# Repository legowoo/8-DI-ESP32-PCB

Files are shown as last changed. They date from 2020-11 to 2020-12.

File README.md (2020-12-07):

# 8-DI-ESP32-PCB
A printed circuit board that enables a ESP32 to interface with digital inputs up to 28VDC.

# Features
- 8 Galvanically isolated inputs
- Pluggable terminal blocks for connecting sensors
- Supports 12 and 24VDC sensors
- ESD protected inputs
- Reverse polarity protection
- Over current protection

# Technical Specification
- ESP32 Input voltage 5-16VDC
- Sensor Input voltage 5-28VDC (with 3/4W input resistors)
- Maximum input current draw 12mA
- Maximum board power draw ~10W

# Schematic
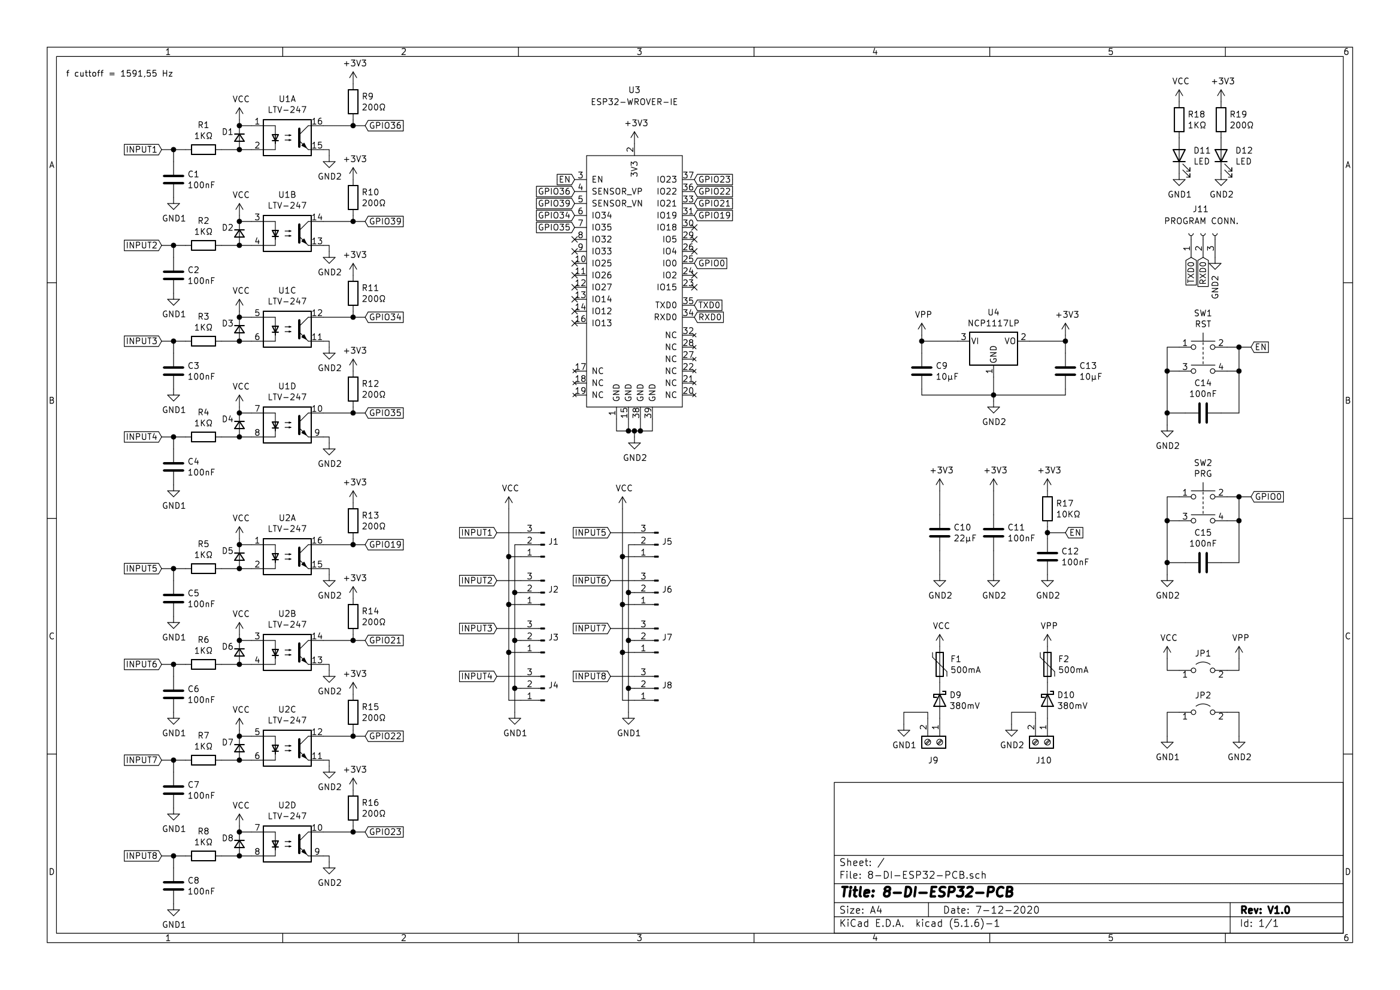
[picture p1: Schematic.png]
Schematic
  

# How to use
- J9: Screw terminal for supplying voltage to the sensors that are connected to the optocouplers. Input voltage range: 5-24VDC
- J10: Screw terminal for supplying voltage to the ESP itself. Input voltage range: 5-12VDC

- D11: Led to indicate the presents/absent of a voltage on the VCC rail (J9).
- D12: Led to indicate the presents/absent of the +3V3 rail (J10).

- JP1: Jumper to connect the VCC to VPP. Used to remove the Galvanic isolation between the sensors and ESP.  
**Only populate this jumper if one voltage source is being used!**
- JP2: Jumper to connect GND1 to GND2. Used to remove the Galvanic isolation between the sensors and ESP.

- J1-J8: Each digital input has its own header connected to the ESP. Pinout from left to right: 1=VCC, 2=GND and 3=GPIO

- SW1: Resart the ESP
- SW2: put the ESP in program mode if the ESP is booting

- J11: Program connector. Connect any +3V3 UART programmer to write a program to the ESP.  
note: the ESP needs to be manualy set to program mode via SW1 and SW2.

# I/O mapping:  
- J1 -> GPIO36
- J2 -> GPIO39
- J3 -> GPIO34
- J4 -> GPIO35
- J5 -> GPIO19
- J6 -> GPIO21
- J7 -> GPIO22
- J8 -> GPIO23

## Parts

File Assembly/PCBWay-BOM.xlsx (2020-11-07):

 |  |  | xxxx xxxx xxxxx xxPCS BOM
Item # | *Designator | *Qty | Manufacturer | *Mfg Part # | Description / Value | *Package/Footprint | Type | Your Instructions / Notes
1 | C9, C13 | 2 | Würth Elektronik | 865080642006 | Aluminum Electrolytic Capacitors 10uF, 50VDC, 20% | Capacitor 5x5.4mm | SMD
2 | C10 | 1 | Würth Elektronik | 865080643008 | Aluminum Electrolytic Capacitors 22uF, 50VDC, 20% | Capacitor 6.3x5.4mm | SMD
3 | C1-C8, C11, C12, C14 | 11 | Würth Elektronik | 885012207098 | MLCC X7R 0.1 uF, 50VDC, 10% | 0805 | SMD
4 | D1-D8 | 8 | ON Semiconductor | BAS21HT1G | General Purpose diode | SOD-323 | SMD
5 | D9, D10 | 2 | Nexperia | PMEG3005EGWX | Schottky Diodes, 380mV, 500mA | SOD-123 | SMD
6 | D11, D12 | 2 | Würth Elektronik | 156120VS75000 | Green LED, 2V, 20mA | 1206 | SMD
7 | F1, F2 | 2 | Bel Fuse | 0ZCJ0025AF2E | PPTC Fuse, 250mA hold, 500mA trip | 1206 | SMD
8 | J1-J8 | 8 | CUI Devices | TBP02R2-381-03BE | Terminal block, pluggable, P3.81mm, receptical, 3 poles | TerminalBlock 3 poles P3.81mm | thru-hole
9 | J9, J10 | 2 | CUI Devices | TB007-508-02BE | Terminal block, screw type, P5.08mm, 2 poles | TerminalBlock 2 poles P5.08mm | thru-hole
10 | J11 | 1 | *Generic* | / | General Purpose 1x03 pin socket P2.54 | PinSocket 1x03 P2.54mm | thru-hole
12 | R9-R16, R19 | 9 | Yageo | RC1206FR-07200RL | Resistors 200 OHM 1% 250mW | 1206 | SMD
13 | R17 | 1 | Yageo | RC1206FR-0710KL | Resistors 10K OHM 1% 250mW | 1206 | SMD
14 | R1-R8, R18 | 9 | Yageo | RC1206FR-071KL | Resistors 1K OHM 1% 250mW | 1206 | SMD
15 | SW1, SW2 | 2 | C&K | PTS647SM38SMTR2LFS | Tactile Switches, 1.8N 3.8mm H, G leads | Custom 4,5x4,5mm switch | SMD
16 | U1, U2 | 2 | Lite-On | LTV-247 | Transistor Output Optocouplers 4CH | SOP-16 P1.27mm | SMD
17 | U3 | 1 | Espressif Systems | M213EH6464UH3Q0 | ESP32-WROVER-IE, ESP32-D0WD-V3, 64Mbit PSRAM, 8 MB SPI flash, IPEX connector | ESP32-WROVER-IE | SMD | This is the version with 8 MB SPI flash
18 | U4 | 1 | ON Semiconductor | NCP1117LPST33T3G | 3.3V LDO Voltage Regulators | SOT-223-3 | SMD

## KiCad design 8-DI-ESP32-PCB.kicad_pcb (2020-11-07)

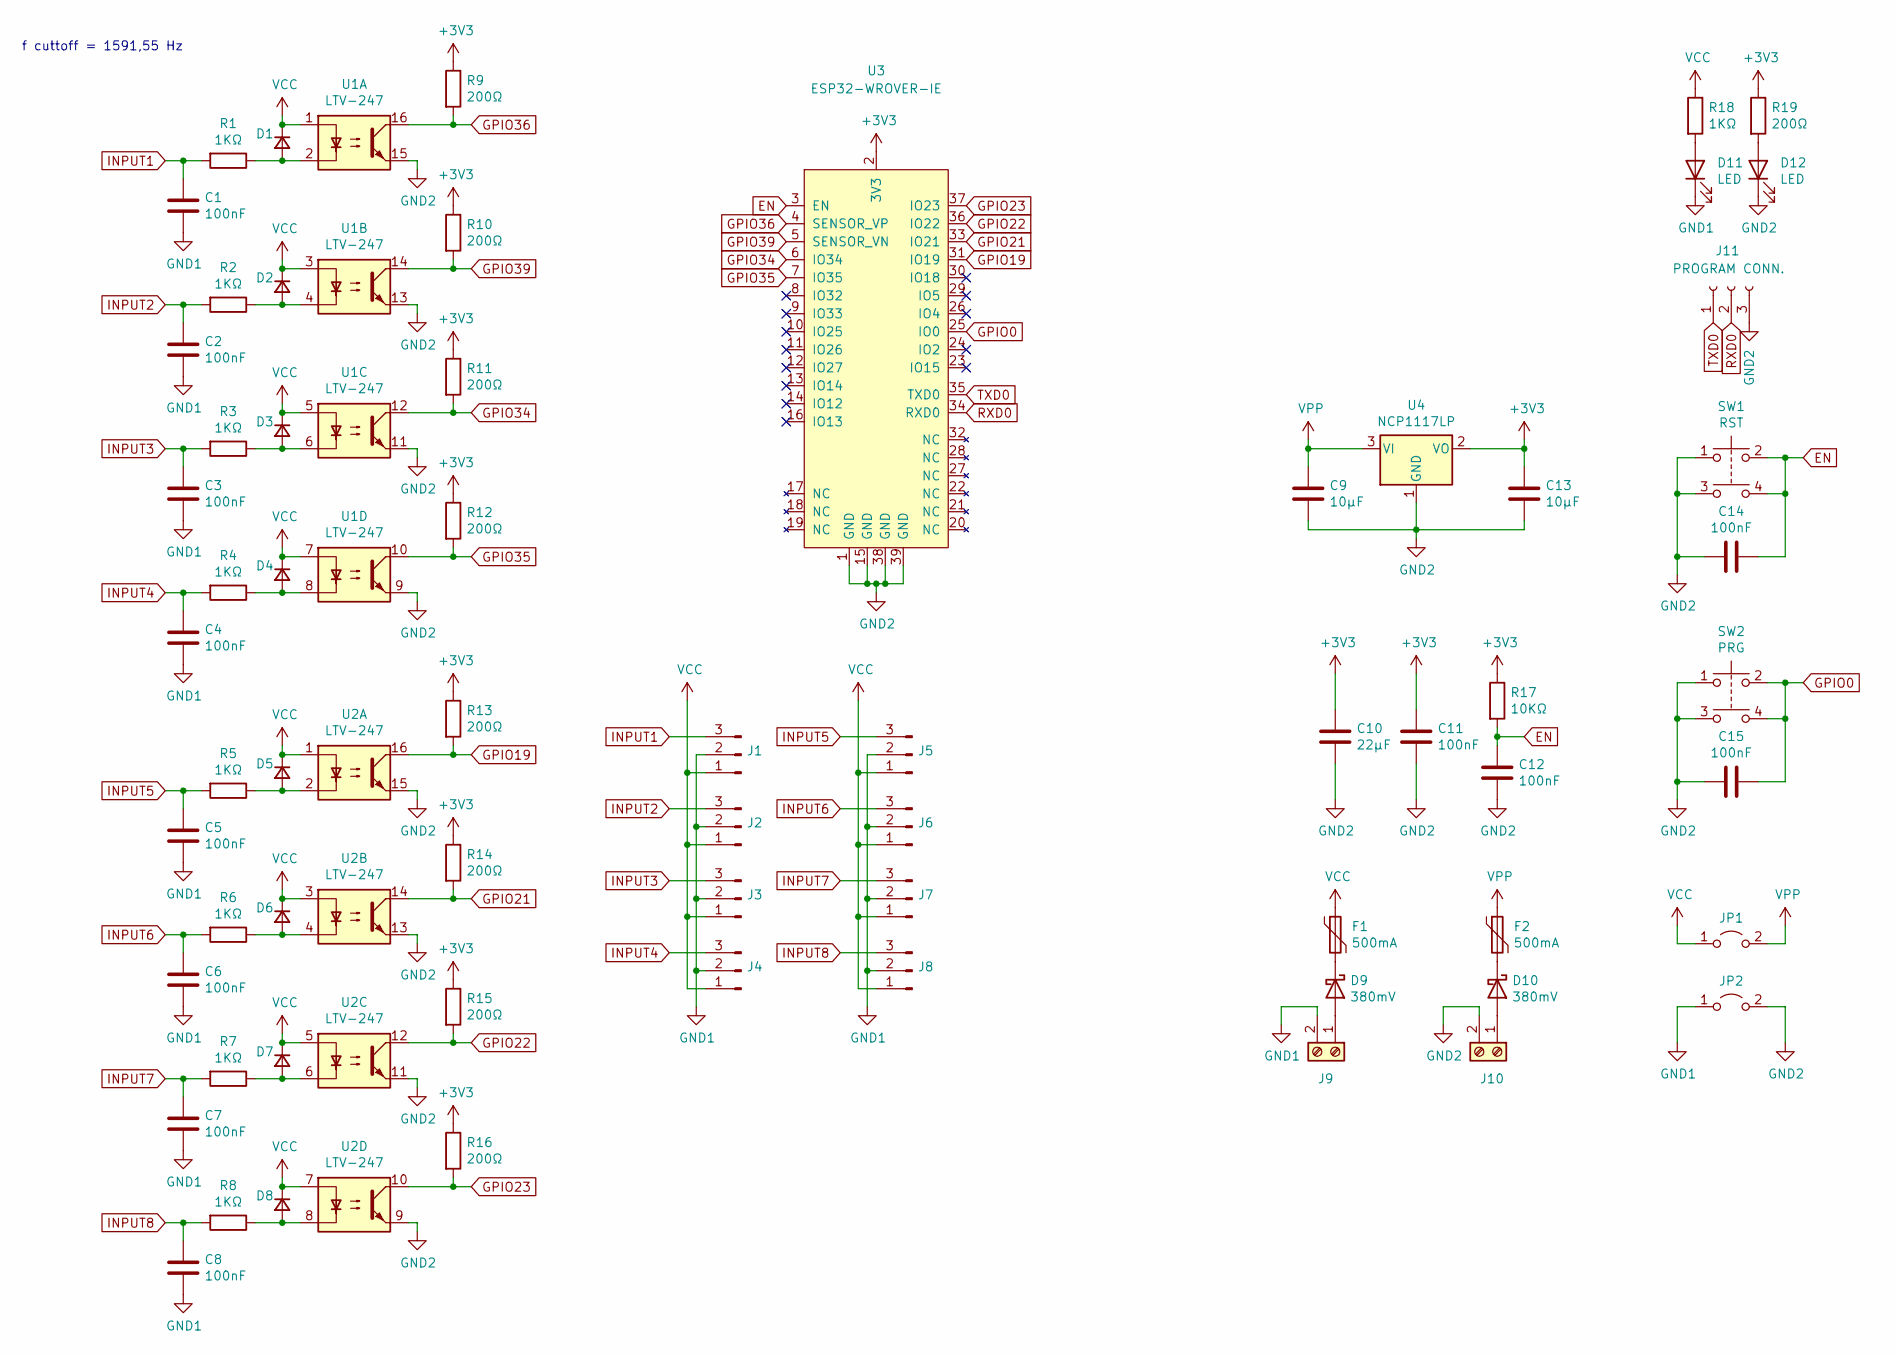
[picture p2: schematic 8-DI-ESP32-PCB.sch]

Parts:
C1, C2, C3, C4, C5, C6, C7, C8, C11, C12, C14, C15: 100nF; C_0805_2012Metric_Pad1.15x1.40mm_HandSolder; MPN 885012207098
C9, C13: 10µF; C_Elec_5x5.4; MPN 865080642006
C10: 22µF; C_Elec_6.3x5.4; MPN 865080643008
D1, D2, D3, D4, D5, D6, D7, D8: D_ESD; D_SOD-323_HandSoldering; MPN BAS21HT1G
D9, D10: 380mV; D_SOD-123F; MPN PMEG3005EGWX
D11, D12: LED; LED_1206_3216Metric; MPN 156120VS75000
F1, F2: 500mA; Fuse_1206_3216Metric_Pad1.42x1.75mm_HandSolder; MPN 0ZCJ0025AF2E
J1, J2, J3, J4, J5, J6, J7, J8: Conn_01x03_Male; CUI_TBP02R2-381-03BE; MPN TBP02R2-381-03BE
J9, J10: Screw_Terminal_01x02; CUI_TB004-508-02BE; MPN TB007-508-02BE
J11: PROGRAM CONN.; PinSocket_1x03_P2.54mm_Vertical
JP1, JP2: Jumper_2_Open; PinHeader_1x02_P2.54mm_Vertical
R1, R2, R3, R4, R5, R6, R7, R8, R18: 1KΩ; R_1206_3216Metric_Pad1.42x1.75mm_HandSolder; MPN RC1206FR-071KL
R9, R10, R11, R12, R13, R14, R15, R16, R19: 200Ω; R_1206_3216Metric_Pad1.42x1.75mm_HandSolder; MPN RC1206FR-07200RL
R17: 10KΩ; R_1206_3216Metric_Pad1.42x1.75mm_HandSolder; MPN RC1206FR-0710KL
SW1: RST; PTS647SM38SMTR2LFS; MPN PTS647SM38SMTR2LFS
SW2: PRG; PTS647SM38SMTR2LFS; MPN PTS647SM38SMTR2LFS
U1, U2: LTV-247; SOP-16_4.4x10.4mm_P1.27mm; MPN LTV-247
U3: ESP32-WROVER-IE; MPN M213EH2864UH3Q0
U4: NCP1117LP; SOT-223-3_TabPin2; MPN NCP1117LPST33T3G

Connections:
+3V3: C10.1, C11.1, C13.1, R9.1, R10.1, R11.1, R12.1, R13.1, R14.1, R15.1, R16.1, R17.1, R19.1, U3.2 (3V3), U4.2 (VO)
EN: C12.1, C14.1, R17.2, SW1.2, SW1.4, U3.3 (EN)
GND1: C1.2, C2.2, C3.2, C4.2, C5.2, C6.2, C7.2, C8.2, D11.1 (K), J1.2, J2.2, J3.2, J4.2, J5.2, J6.2, J7.2, J8.2, J9.2, JP2.1 (A)
GND2: C9.2, C10.2, C11.2, C12.2, C13.2, C14.2, C15.2, D12.1 (K), J10.2, J11.3, JP2.2 (B), SW1.1, SW1.3, SW2.1, SW2.3, U1.9, U1.11, U1.13, U1.15, U2.9, U2.11, U2.13, U2.15, U3.1 (GND), U3.15 (GND), U3.38 (GND), U3.39 (GND), U4.1 (GND)
GPIO0: C15.1, SW2.2, SW2.4, U3.25 (IO0)
GPIO19: R13.2, U2.16, U3.31 (IO19)
GPIO21: R14.2, U2.14, U3.33 (IO21)
GPIO22: R15.2, U2.12, U3.36 (IO22)
GPIO23: R16.2, U2.10, U3.37 (IO23)
GPIO34: R11.2, U1.12, U3.6 (IO34)
GPIO35: R12.2, U1.10, U3.7 (IO35)
GPIO36: R9.2, U1.16, U3.4 (SENSOR_VP)
GPIO39: R10.2, U1.14, U3.5 (SENSOR_VN)
INPUT1: C1.1, J1.3, R1.2
INPUT2: C2.1, J2.3, R2.2
INPUT3: C3.1, J3.3, R3.2
INPUT4: C4.1, J4.3, R4.2
INPUT5: C5.1, J5.3, R5.2
INPUT6: C6.1, J6.3, R6.2
INPUT7: C7.1, J7.3, R7.2
INPUT8: C8.1, J8.3, R8.2
unnamed: D1.2 (A), R1.1, U1.2
unnamed: D2.2 (A), R2.1, U1.4
unnamed: D3.2 (A), R3.1, U1.6
unnamed: D4.2 (A), R4.1, U1.8
unnamed: D5.2 (A), R5.1, U2.2
unnamed: D6.2 (A), R6.1, U2.4
unnamed: D7.2 (A), R7.1, U2.6
unnamed: D8.2 (A), R8.1, U2.8
unnamed: D9.1 (K), F1.2
unnamed: D9.2 (A), J9.1
unnamed: D10.1 (K), F2.2
unnamed: D10.2 (A), J10.1
unnamed: D11.2 (A), R18.2
unnamed: D12.2 (A), R19.2
RXD0: J11.2, U3.34 (RXD0)
TXD0: J11.1, U3.35 (TXD0)
VCC: D1.1 (K), D2.1 (K), D3.1 (K), D4.1 (K), D5.1 (K), D6.1 (K), D7.1 (K), D8.1 (K), F1.1, J1.1, J2.1, J3.1, J4.1, J5.1, J6.1, J7.1, J8.1, JP1.1 (A), R18.1, U1.1, U1.3, U1.5, U1.7, U2.1, U2.3, U2.5, U2.7
VPP: C9.1, F2.1, JP1.2 (B), U4.3 (VI)

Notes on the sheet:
f cuttoff = 1591,55 Hz

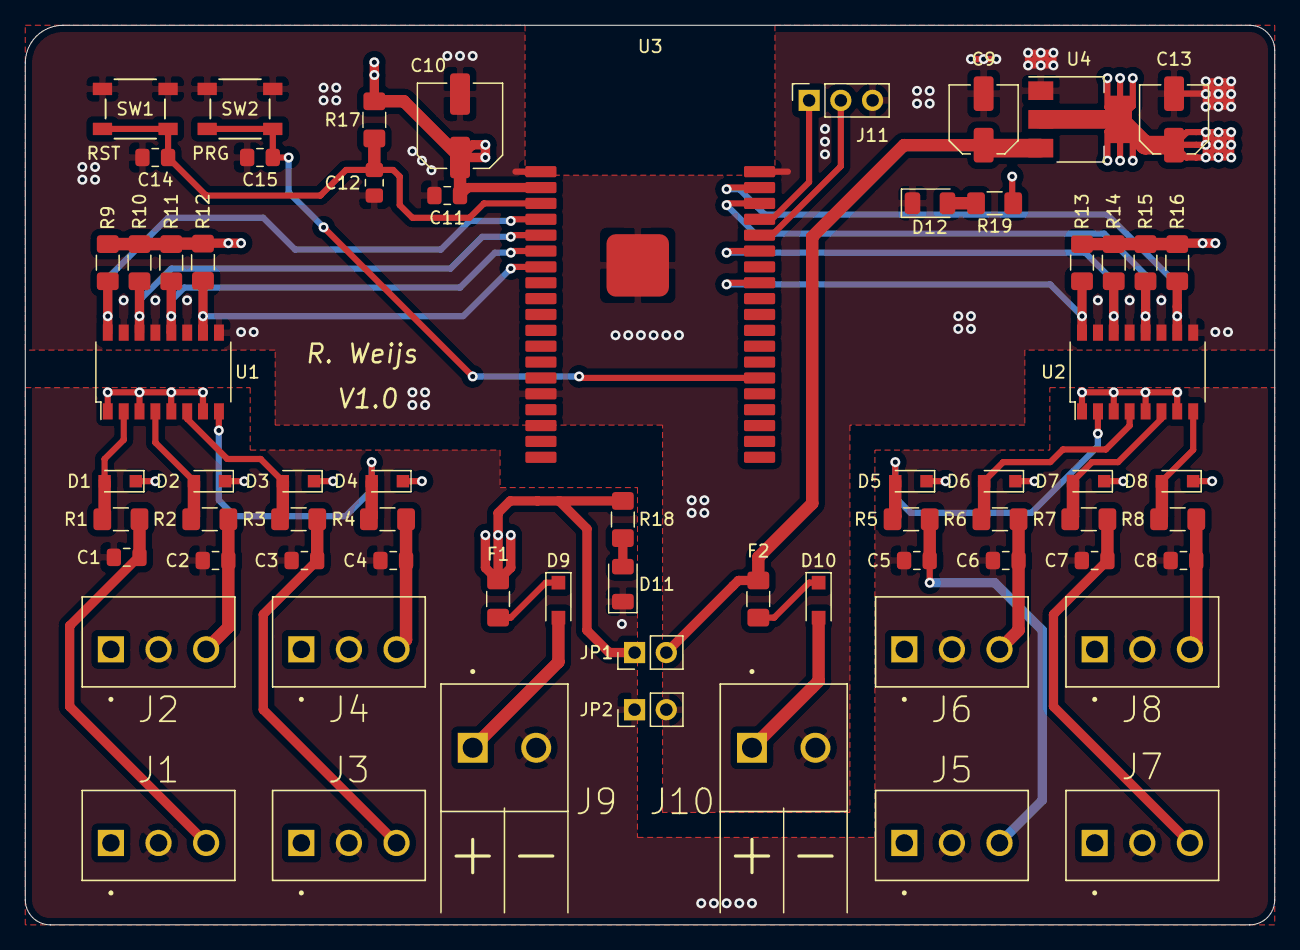
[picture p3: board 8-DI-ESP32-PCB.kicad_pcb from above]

Board: 4 copper layers, 100.0 x 72.0 mm, 67 parts (0 on the bottom side), 39 nets.

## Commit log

2020-11-07 intial commit
    [8-DI-ESP32-PCB-B_Cu.gbr, 8-DI-ESP32-PCB-B_Mask.gbr, 8-DI-ESP32-PCB-B_Paste.gbr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]
2020-11-07 clean-up temp. files
    [8-DI-ESP32-PCB.sch]

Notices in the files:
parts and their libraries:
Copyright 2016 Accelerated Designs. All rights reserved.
